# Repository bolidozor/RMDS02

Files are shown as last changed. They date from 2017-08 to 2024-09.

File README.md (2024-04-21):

# Radio Meteor Detection Station RMDS02F

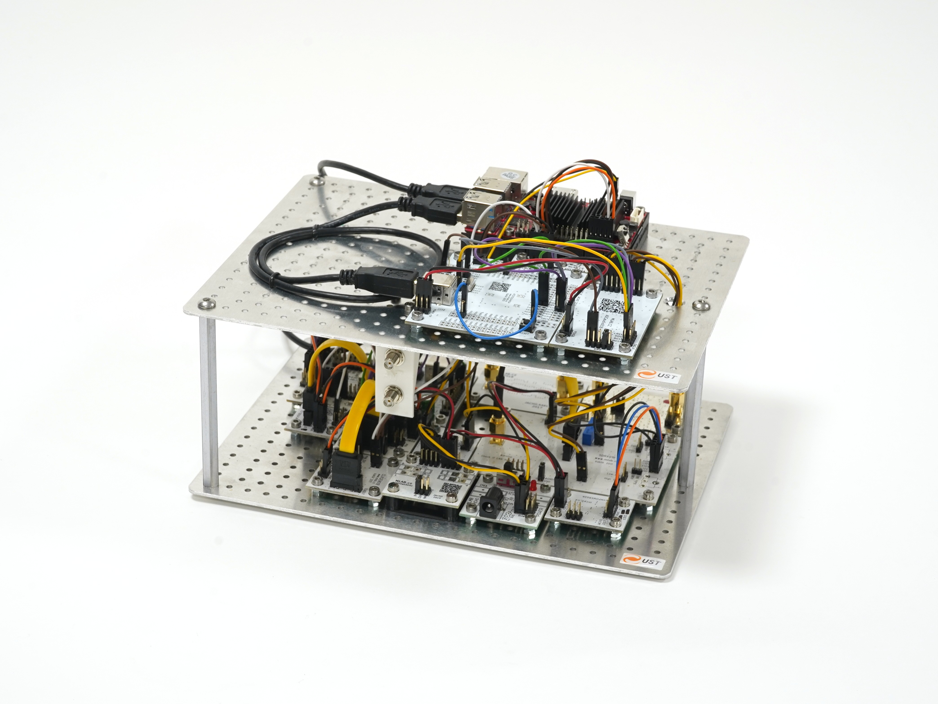
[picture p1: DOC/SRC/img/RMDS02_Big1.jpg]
RMDS02 Station RMDS02E station


The Radio Meteor Detection Station RMDS02F is a state-of-the-art system utilizing a software-defined radio (SDR) receiver set specifically configured for the detection of meteor trails using radio signals. The primary source of detection signals is the military GRAVES radar, which offers superior stability and power output, enabling effective meteor detection across nearly all of Europe. The station does not need any maitanance. The only requirement is power supply and internet connection on the observation site. 

## Features

- **Software-Defined Radio (SDR)**: The core of the RMDS02F is its SDR receiver, which allows for advanced signal processing techniques to be applied, enhancing detection capabilities.
- **GPS Synchronization**: The system includes GPS time and frequency synchronization which aids in determining inter-station reflection variations and the Doppler shift of the detected signals.
- **Enhanced Power Supply**: The station's power supply system has been upgraded to ensure reliable and consistent operation.
- **Single Board ARM Computer**: The station utilizes a single board ARM computer to process data and manage the detection system.
- **SDR-Widget Digitalization**: Signals are digitized using an SDR-Widget, ensuring high-quality data capture for advanced analysis.

## Advantages of Using GRAVES Radar

Utilizing the GRAVES military radar signal provides several advantages over traditional methods that use TV transmitters for meteor detection:
- **High Stability and Reliability**: The military-grade transmission offers unmatched signal stability and consistency.
- **Powerful Transmission**: With its enormous power output, the GRAVES radar system can cover a vast geographic area, making it possible to detect meteors throughout Europe.

## Description

The RMDS02F is an advanced radio meteor trail detection system. It is designed for accurate and efficient detection of meteors by utilizing the reflective properties of meteor trails in the upper atmosphere. The integration of GPS provides time and frequency stabilization that is crucial for analyzing inter-station signal variations and capturing Doppler shifts in the meteor trail reflections.

For further information and updates, please refer to the [Bolidozor documentation](https://wiki.bolidozor.cz/doku.php?id=en:rmds).

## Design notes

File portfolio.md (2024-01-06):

---
title: "Radio Meteor Detection Station"
excerpt: "The RMDS02 is the basic SDR receiver set for radio detection of meteor trails."
header:
  image: products/RMDS/DOC/SRC/img/RMDS02E_Big.jpg
  teaser: products/RMDS/DOC/SRC/img/RMDS02E_Big.jpg
  overlay_color: "#000"
  overlay_filter: "0.5"
  overlay_image: products/RMDS/DOC/SRC/img/RMDS02E_Big.jpg
---

# Radio Meteor Detection Station RMDS02E

The device presents the basic SDR receiver set for radio detection of meteor trails. Compared to other methods, its main advantage is in the fact that it uses a software-defined receiver that enables various advanced signal processing techniques.

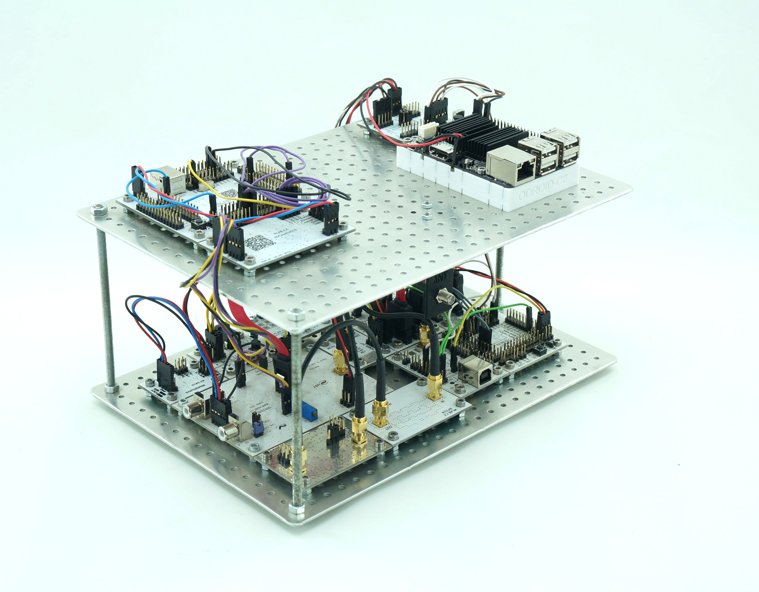
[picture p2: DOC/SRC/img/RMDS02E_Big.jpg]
RMDS02E Station RMDS02E station


## Meteor detection using GRAVES radar

The advantages of using the signal from military GRAVES radar, compared to the conventional observations using TV transmitters, include the stability and enormous power output of the military system transmission. This makes it possible to utilize it in almost every country in Europe.

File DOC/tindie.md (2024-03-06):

Embark on an unparalleled journey into the cosmos with the latest Radio Meteor Detection Station (RMDS). Designed for the technically savvy amateur astronomer, RMDS combines cutting-edge software-defined radio (SDR) technology with precision engineering to offer an unmatched meteor observation experience.

**🔭 Key Features:**

- **High-Precision SDR Technology:** Utilize state-of-the-art SDR for real-time meteor trail detection, capturing every celestial event with exceptional clarity.
- **Integration with GRAVES Radar:** Leverage the powerful and stable signal of the military-grade GRAVES radar, ensuring comprehensive coverage across Europe for reliable meteor detection.
- **Community Collaboration:** Join a network of stations through initiatives like [Bolidozor](https://www.bolidozor.cz/), fostering a collaborative environment for data sharing and analysis.
- **Advanced Data Analysis:** With shared platforms, contribute to and benefit from a collective pool of meteor detection data, enhancing scientific inquiry and understanding.

**🌠 Technical Specifications:**

- **SDR-Based Detection Module:** Tailored high dynamic signal processing, enabling the capture of meteor trails with high sensitivity.
- **Optimized Antenna System:** Optionally includes a ground-plane antenna designed for signal reception even from a balcony.
- **Customizable Software Interface:** Feature-rich software for detailed analysis, including real-time monitoring, data logging, and visualization tools.
- **Robust Construction:** Self-tuning SDR ensures year-round operation in a variety of climates.

**💡 Ideal for**

- Amateur astronomers seeking a dive into radio astronomy and meteor detection.
- Science educators and researchers looking for a reliable tool to enhance study and observation.
- Tech enthusiasts interested in the application of SDR technology in astronomical observations.

**Elevate Your Astronomy Experience**

The RMDS is more than just a tool; it's your gateway to exploring the mysteries of the night sky in ways previously invisible. With its superior technology, collaborative potential, and comprehensive support, the RMDS is the perfect addition to the tools of any amateur astronomer ready to take their passion to new heights.

Embark on a celestial journey with the Radio Meteor Detection Station and witness the wonders of the universe like never before.

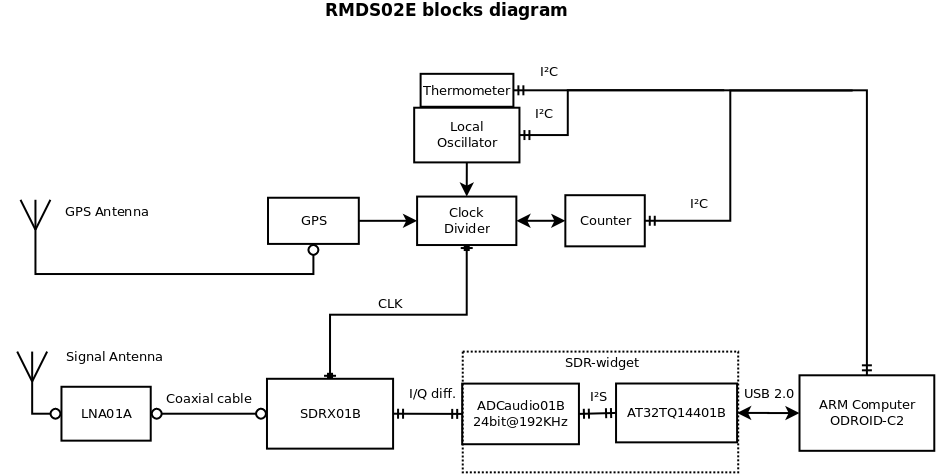
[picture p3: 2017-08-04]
DOC/SRC/img/RMDS02E_blocks.png

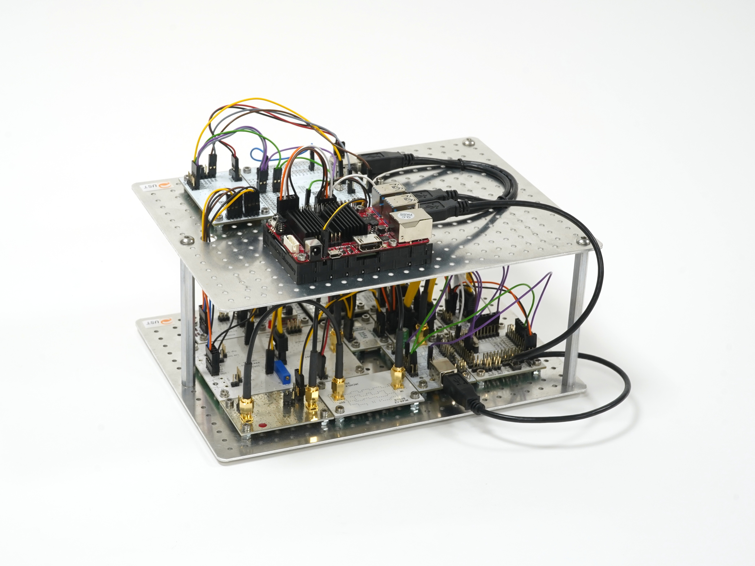
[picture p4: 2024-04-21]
DOC/SRC/img/RMDS02_Big2.jpg

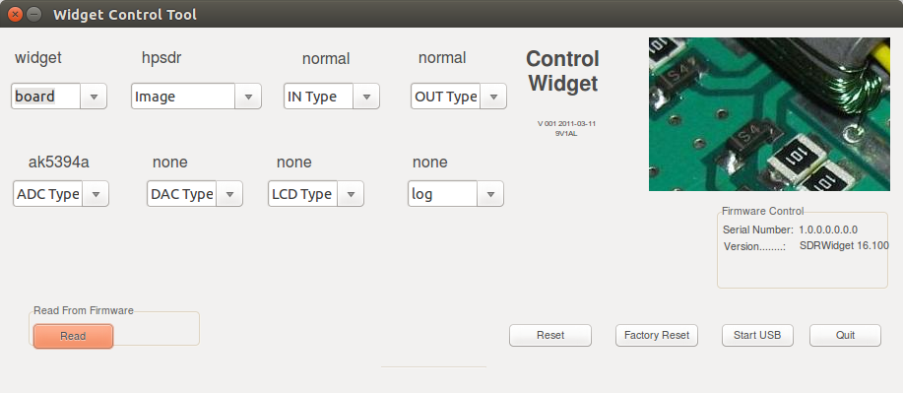
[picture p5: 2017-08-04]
DOC/SRC/img/SDR-widget_settings.png

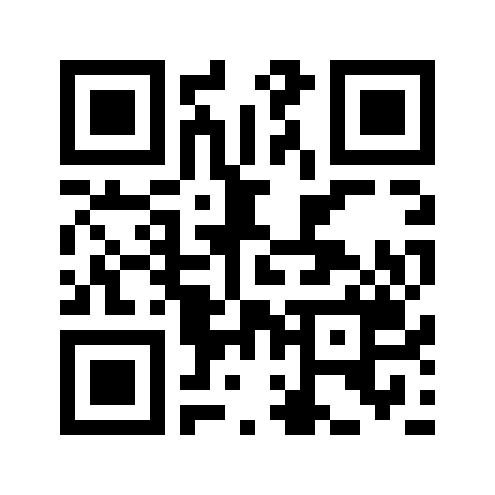
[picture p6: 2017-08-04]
DOC/SRC/img/Bolidozor_web_QR.png

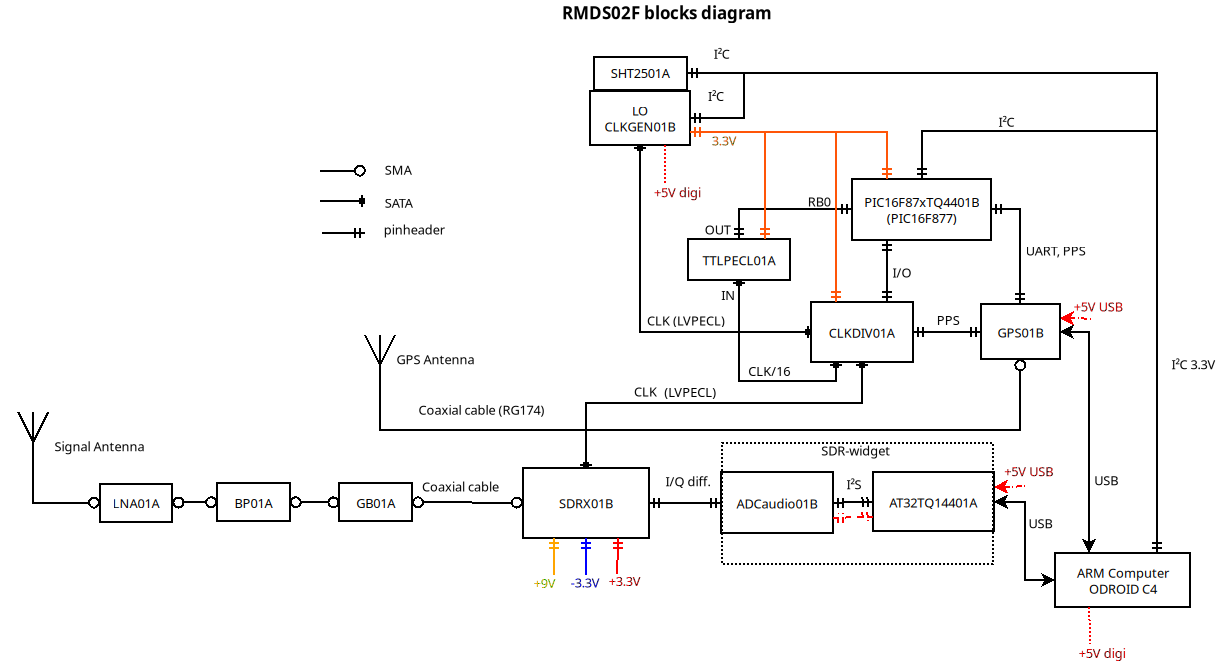
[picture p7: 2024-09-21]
SCH/RMDS02_station.png

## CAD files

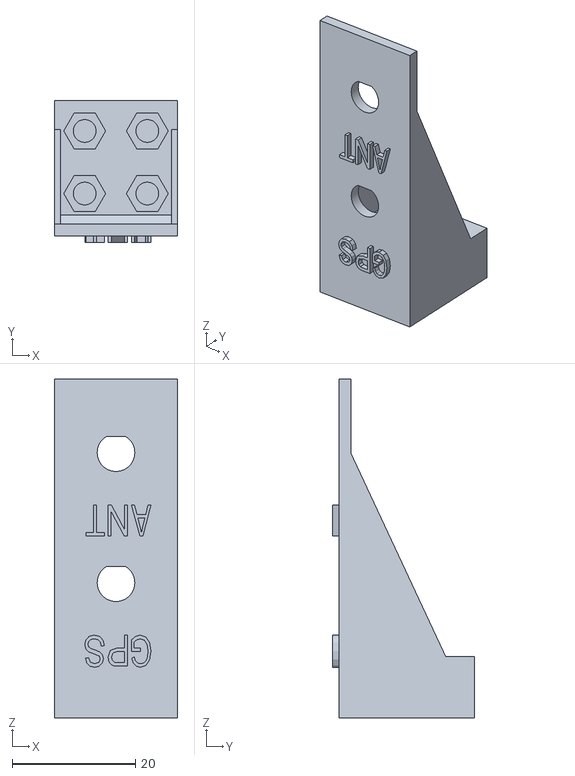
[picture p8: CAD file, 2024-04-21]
CAD/connectors_holder.stl
20.0 x 23.0 x 55.0

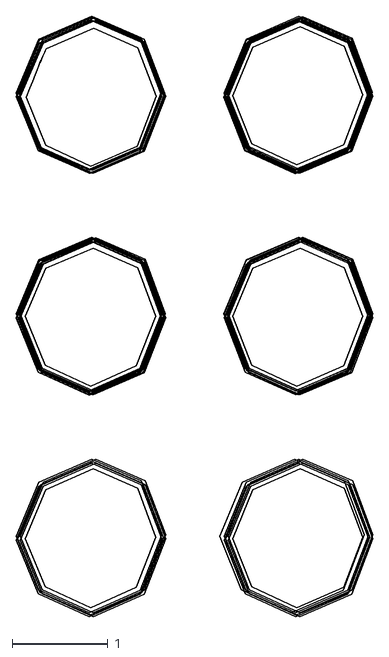
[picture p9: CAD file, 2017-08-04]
CAD/src/braille.dxf
3.72 x 6.26

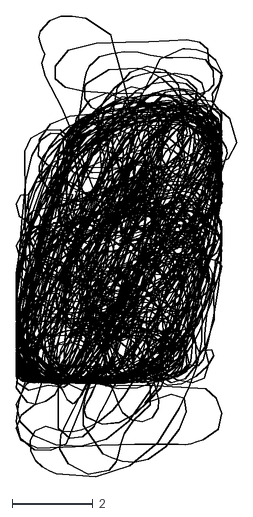
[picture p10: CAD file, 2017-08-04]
CAD/src/knewave.dxf
5.46 x 11.4

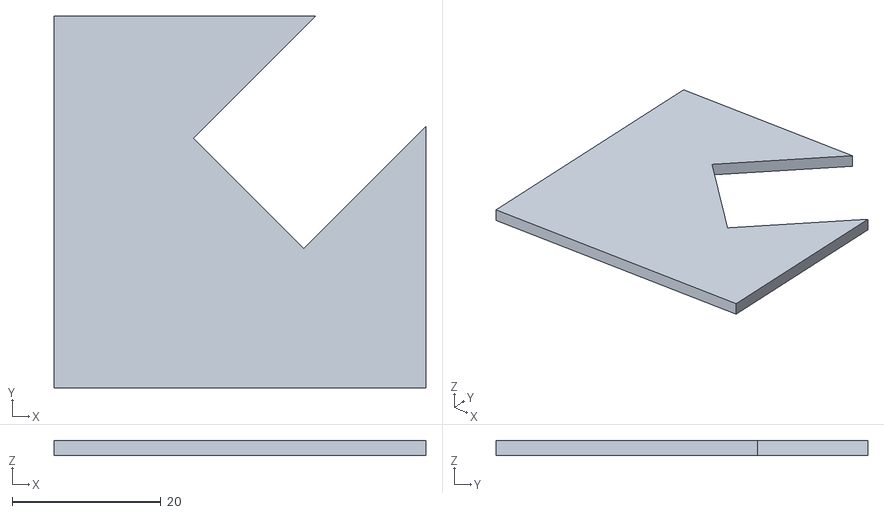
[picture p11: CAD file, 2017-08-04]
CAD/template_terarium_pad.stl
50.0 x 50.0 x 2.00

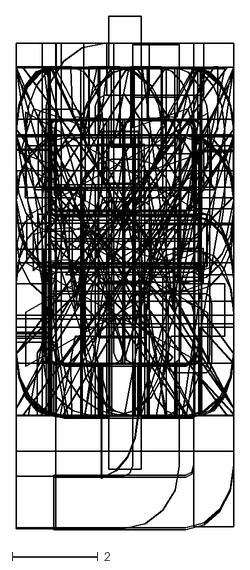
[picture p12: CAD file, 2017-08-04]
CAD/src/orbitron.dxf
5.08 x 12.0

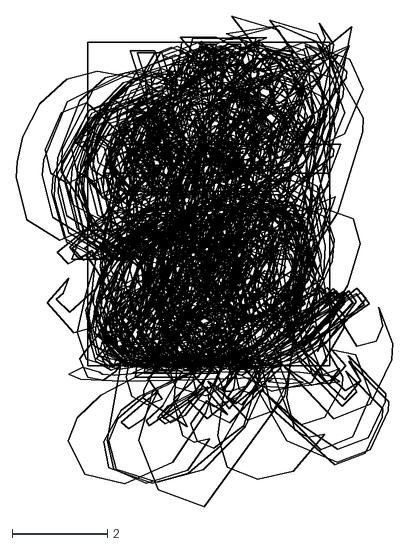
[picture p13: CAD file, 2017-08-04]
CAD/src/BlackRose.dxf
7.90 x 10.3

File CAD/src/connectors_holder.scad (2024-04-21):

use<Write.scad>
$fn=100;

x_size = 20;           // horizontal outer size of the pedestal. 
y_size = 20;           // 
mount_hole = 3.5;
nut_size = 6.8;
SMA_dia = 6.1;
SMA_flat = 3.15;
thickness = 10;         //
wall_thickness = 2;
height = 55;

mount_hole = 3.7;
clear = 0.175;

MLAB_grid = 10.16;

x_holes = floor(x_size / MLAB_grid);
y_holes = floor(y_size / MLAB_grid);

MLAB_grid_xoffset = (x_size - (x_holes * MLAB_grid))/2;
MLAB_grid_yoffset = (y_size - (y_holes * MLAB_grid))/2;

//Top part

union () {

    difference(){
        cube([x_size, y_size, height]);
        translate([1, 0, 0]) cube([x_size-2, y_size+0.1, height+0.1]);
        translate([-0.1, y_size, 0]) rotate([25, 0, 0]) cube([x_size+0.2, y_size+10, height+10]);
    }

    difference () {
                cube([x_size, y_size , thickness ]);

// MLAB grid holes
        grid_list = [for (j = [MLAB_grid_xoffset : MLAB_grid: x_size], i = [MLAB_grid_yoffset :MLAB_grid: y_size])  [j, i] ];
            
        for (j = grid_list) {
                translate (concat(j, [0]))
                    cylinder (h = 3, r= nut_size/2, $fn=6);
                translate (concat(j, [3.2]))  // one solid layer for slicer (the holes will be pierced on demand )
                    cylinder (h = thickness /3, r= mount_hole/2, $fn=30);
                translate (concat(j, [6.0]))
                    cylinder (h = 10, r= nut_size/2, $fn=6);
        }  
    };
// vertical to horizontal brick connection
    translate ([ 0, 0, thickness - sqrt(2 * wall_thickness*wall_thickness) / 2])  // move to correct positon on square diagonal  
        rotate([45,0,0])
            cube([x_size, wall_thickness , wall_thickness ]);

    difference  () {

        translate ([0, -wall_thickness, 0])    // vertical brick
            cube([y_size, wall_thickness , height ]);
        
// SMA connector holes
        translate ([ x_size/2, wall_thickness/2, (height - thickness)/3  + thickness - SMA_dia/2])    
            rotate([90,0,0]) {
                difference  () {
                    cylinder (h = 2*wall_thickness, r= SMA_dia/2, $fn=50);
                        translate([ 0, SMA_flat , wall_thickness/2 + wall_thickness ]) 
                            cube([SMA_dia, 1 , thickness ], center=true);
                }
            }

        translate ([ x_size/2, wall_thickness/2, 2*(height - thickness)/3  + thickness  + SMA_dia/2 ])    
            rotate([90,0,0]){
                difference  () {
                    cylinder (h = 2*wall_thickness, r= SMA_dia/2, $fn=50);
                        translate([ 0, SMA_flat , wall_thickness/2 + wall_thickness ]) 
                            cube([SMA_dia, 1 , thickness ], center=true);
                }
 
           }
           
    }
// texts
    
        translate ([ x_size/2, wall_thickness/2, (height - thickness)/3  + thickness - SMA_dia/2])    
            rotate([90,0,0]) {
                translate([ 0, -11, wall_thickness/2 + wall_thickness ]) 
                    rotate([0,0,180])
                        write("GPS",h=5,t=2,space= 1.1, font = "Letters.dxf", center=true);
            }
            
            translate ([ x_size/2, wall_thickness/2, 2*(height - thickness)/3  + thickness  + SMA_dia/2 ])    
            rotate([90,0,0]){
                translate([ 0, -11, wall_thickness/2 + wall_thickness]) 
                    rotate([0,0,180])
                        write("ANT",h=5,t=2, space= 1.1, font = "Letters.dxf",center=true);
            }
               
           
}

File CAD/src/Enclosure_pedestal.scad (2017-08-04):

pedestal_height = 130;  // height of pedestal
x_size = 250;           // horizontal outer size of the aquarium pedestal. 
y_size = 300;           // 
thickness = 10;         // thickness of walls
rim_height = 10;        // height of upper rim for fixing the aquarium in position.

difference () {
	cube([x_size, y_size ,pedestal_height]);
        translate ([thickness, thickness, pedestal_height - rim_height)
	        cube([x_size - 2* thickness, y_size - 2* thickness, thickness]);

	    cube([x_size - 2* thickness, y_size - 2* thickness, pedestal_height - rim_height - thickness]);
}

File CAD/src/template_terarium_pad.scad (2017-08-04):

hrana=50;
vzdalenost_od_rohu=37;
sila_materialu=2;

pad_sirka=21;
pad_delka=50;

difference()
{
//základní materiál
cube([hrana,hrana,sila_materialu],false);

rotate([0, 0, -45])
translate([0,vzdalenost_od_rohu+ pad_delka/2, 0])
cube([pad_sirka,pad_delka,2*sila_materialu+0.1],true);
    }

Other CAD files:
CAD/src/Letters.dxf
CAD/src/terarium_pad.scad
CAD/src/Write.scad

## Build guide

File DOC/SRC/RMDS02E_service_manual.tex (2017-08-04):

\documentclass[12pt,a4paper,oneside]{article}
\usepackage[colorlinks=true]{hyperref}
\usepackage[utf8]{inputenc}
\usepackage[czech]{babel}
\usepackage{graphicx}
\usepackage{pdfpages}
\textwidth 16cm \textheight 25cm
\topmargin -1.3cm 
\oddsidemargin 0cm
\pagestyle{empty}
\begin{document}
\title{Radiová meteorická detekční stanice RMDS02D}
\author{Jakub Kákona, kaklik@mlab.cz }
\maketitle

\begin{abstract}
Servisní manuál k rádiové detekční stanici RMDS02D sítě Bolidozor.
\end{abstract}

\begin{figure} [htbp]
\begin{center}
\includegraphics [width=120mm] {./img/RMDS02D_showcase1.JPG} 
\end{center}
\end{figure}

\begin{figure} [b]
\includegraphics [width=25mm] {./img/Bolidozor_web_QR.png} 
\end{figure}

\newpage
\tableofcontents

\section{Základní technické parametry}
\begin{table}[htbp]
\begin{center}
\begin{tabular}{|c|c|p{5cm}|}
\hline
\multicolumn{1}{|c|}{Parametr} & \multicolumn{1}{|c|}{Hodnota} & \multicolumn{1}{|c|}{Poznámka} \\ \hline
Napájení analogových obvodů & $\pm$12V &  cca 35mA \\ \hline
Napájení digitálních obvodů & 2x +5V &  2A \\ \hline
Napájení předzesilovače  & 9-12V &  500 mA \footnote{Chráněno vratnou PTC pojistkou 750mA na desce přijímače} \\ \hline
Pracovní Frekvenční rozsah  & 0,5 - 200 MHz & Obvykle 143.05 MHz $\pm$ 192 kHz \\ \hline
Vzorkování I/Q signálu  & 16bit@96kHz & \\ \hline
Celkový zisk & 60-90 dB & Volitelně podle konfigurace LNA \footnote{Lze ovlivnit jumperem na desce přijímače}\\ \hline
Celkové šumové číslo & $<$ 10 dB & \\ \hline
Minimální detekovatelný signál & -135dBm  &  Při konfiguraci v síti Bolidozor.\\ \hline
Přesnost časové synchronizace &  65ns (1$\sigma$) &  Používán signál GPS L1.\\ \hline
Rozlišení kontrolního měření frekvence LO &  0.1 Hz &  Přesnost je závislá na kvalitě signálu GPS.\\ \hline
\end{tabular}
\end{center}
\end{table}

\newpage

\section{Konstrukce detekční stanice}

\begin{figure}[htbp]
\begin{center}
\includegraphics [width=120mm] {../../SCH/RMDS02D_system.png} 
\end{center}
\caption{Konstrukce antény používané na detekční stanici.}
\end{figure}

\subsection{Přijímací obvody}

Rádiový

\subsection{SDR přijímač}

V přijímací stanici je využíván přijímač MLAB SDRX01B \cite{SDRX01B_pdf}. Jde o SDR přijímač zkonstruovaný původně pro účely amatérské radioastronomie a je proto optimalizovaný pro realizaci škálovatelných rádiových systémů. Přijímač vyžaduje externí lokální oscilátor, který je v případě této konstrukce realizovaný zapojením modulu CLKGEN01B s obvodem Si570, který je řízen přes sběrnici I2C.  Frekvence tohoto lokálního oscilátoru je měřena 3x za minutu a logována do souboru. Po změření se navíc frekvence automaticky koriguje na nastavenou hodnotu. Fázový šum lokálního oscilátoru je maximálně –105~dBc/Hz (Při offsetu 100~Hz)

\begin{figure}[htbp]
\begin{center}
\includegraphics [width=120mm] {./img/SDRX01B_Top_Big.JPG} 
\end{center}
\caption{Hlavní modul přijímače SDRX01B}
\end{figure}

Díky měření frekvence lokálního oscilátoru je ve stanici v podstatě obsažena GPSDO kmitočtová reference, která napájí přijímač. Výstupem přijímače je tak komplexní I/Q signál, který je v této verzi stanice digitalizován externí USB zvukovou kartou Behringer UCA 202 U-CONTROL. Tento audio kodek vzorkuje 48kHz s rozlišením 16bit ve dvou kanálech.  Zvuková karta bude v následující verzi stanice nahrazena digitalizační jednotkou SDR-Widget. Která už může mít vzorkovací hodinový signál též odvozen od hlavního lokálního oscilátoru. 

\subsection{Časová synchronizace}

Časová synchronizace je velmi dúležitá ve vědeckých měřeních. Konstrukce využívá dvě metody časové synchronizace NTP a signál z GPS.  NTP je využíváno pro časovou synchronizaci systémových hodin staničního počítače a používá se i pro generování názvů výstupních datových souborů. Přesnost tohoto synchronizačního kanálu závisí na kvalitě internetového připojení, resp době pingu k NTP serveru.  Proto je na stanici zaveden ještě zdroj časových značek z GPS, který umožňuje značkovat výstupní data s rozlišením až na vzorkovací frekvenci digitalizační jednotky. 
Jako GPS přijímač je ve stanici využíván MLAB modul GPS01A s čipsetem uBlox-LEA6. Použitá GPS anténa je keramická patch s integrovaným předzesilovačem.

\subsubsection{Měření frekvence lokálního oscilátoru}

Stanice je vybavena automatizovaným systémem kontroly lokálního oscilátoru. Zařízení umožňuje měření frekvence lokálního oscilátoru oproti dlouhodobému časovému normálu z GPS. Měření se provádí tak, že signál z lokálního oscilátoru generovaného modulem CLKGEN01B se vydělí modulem CLKDIV01A a vydělený výstupní signál je veden do čítače v PIC16F887. Kde jsou na hrubo počítány tako vydělené hodinové pulzy. 
Modul GPS01A je pak nastaven tak, aby generoval 100us dlouhý impuls každých celých 10s UT.  Tento impuls je pak využit ke zahradlování děličky CLKDIV01A.  Zároveň impuls vede na vstup přerušení PIC16F887 a ten pak provede vyčtení čítače a interních stavů děličky tím, že projde všechny možné dělící poměry a přečte výstupní stav děličky. Výsledkem je absolutně změřený počet pulzů za 10s.  Toto číslo je následně uloženo v registrech mikrokontroleru PIC16F887. Vyčtení těchto registrů proběhne ze staničního počítače přes sběrnici I2C každou 5. 25. a 45. sekundu UT času. \footnote{Měření je takto rozloženo díky tomu, že obsluha I2C probíhá také pod přerušením a při vyčítání může dojít k poškození měřené hodnoty vynecháním přerušení obsluhy čítače.}
Protože při zahradlování děličky dojde k odpojení lokálního oscilátoru od směšovače v SDRX01B, tak na výstupním signálu se objeví impuls s širokým frekvenčním spektrem, který slouží jako časová značka ve výstupních datech.  Časová synchronizace tak zároveň přesně značkuje výstupní data hodinami odvozenými z GPS signálu. Tvar těchto časových značek je navíc odvozen od impulzní odezvy přijímacího řetězce, takže na něm lze pozorovat případné nežádoucí změny parametrů. 

\subsection{Staniční počítač}

Jako staniční počítač je využíván Hardkernel ODROID-U3, což je čtyřjádrový počítač postavený na architektuře ARM. K tomuto počítači je ještě obvykle připojen USB flash disk, který slouží jako krátkodobé uložiště pro zaznamenaná data.  Technické parametry použitého ARM počítače jsou následující: 

\begin{itemize}
\item 1.7GHz Quad-Core processor and 2GByte RAM
\item 10/100Mbps Ethernet with RJ-45 LAN Jack
\item 3 x High speed USB2.0 Host ports
\item Audio codec with headphone jack on board
\item GPIO/UART/I2C ports
\end{itemize}

Komponenty stanice jsou k počítači připojeny přes rozhraní USB: (Zvuková karta, GPS přijímač) a přes rozhraní I2C: (Lokální oscilátor, měření frekvence)

\begin{figure}[htbp]
\begin{center}
\includegraphics [width=140mm] {./img/u3rev05boarddetail.jpg} 
\end{center}
\caption{Deska počítače Hardkernel ODROID-U3}
\end{figure}

\section{Software stanice}

Na staničním počítači je nainstalovaný operační systém linux Lubuntu 14.04 LTS včetně grafického rozhraní xfce.  Grafické rozhraní je na stanici využíváno pro zobrazování stavových informací. (živý waterfall, stav GPS, stav uploadu dat). S datovým tokem z přijímače je zacházeno jako s širokopásmým audio signálem. Proto je pro rozvod  datového toku použit audiosystém JACK. Příklad rozvodu signálu je na obrázku \ref{qjackctl}.

\begin{figure}[htbp]
\centering
\includegraphics [width=120mm] {./img/JACK_audio.png} 
\caption{Rozvod audio signálu v systému JACK.}
\label{qjackctl}
\end{figure}

Jack audio server navíc umožňuje přenášet stream přes lokální síť ethernet a aktuální tok spektra z přijímače je tak možné sledovat i na jiných počítačích viz obr. \ref{Pysdr}.

\begin{figure}[htbp]
\centering
\includegraphics [width=120mm] {./img/meteor_pysdr.jpg} 
\caption{Vzdálené zobrazení toku spektra v programu PySDR. S meteorem označeným MIDI packetem.}
\label{Pysdr}
\end{figure}

\subsection{Záznam dat}

Data jsou na stanici zaznamenávána programem radio-observer, který běží jako klient systému jack, počítá FFT spektra a detekuje meteory podle intenzity signálu v oblasti, kde je předpokládán signál od vysílače. Pokud v této oblasti dojde ke zvýšení intenzity signálu o prahovou hodnotu nad šumem tak je detekován meteor.  Při detekci meteoru vznikne několik záznamů, jednak náhled na frekvenční oblast spektra, kde meteor byl detekován. Potom záznam surových vzorků z přijímače a také záznam do metadatového souboru s parametry signálu detekovaného meteoru (délka odrazu, intenzita signálu, atd.). Datové výstupy jsou ve formátu FITS s kompresí RICE, buď jako navzorkované signály a nebo předpočítané spektrogramy. Všechna naměřená data jsou veřejně dostupná na datovém serveru. 

\subsection{Odesílání záznamů}

Naměřená data jsou ještě na stanici setříděna do stromové adresářové struktury podle času. A následně uploadována přes rsync na hlavní datový server space.astro.cz.

\subsection{Správa stanice}

Na stanici běží ještě další pomocné aplikace, jako sshd server, pro vzdálený přístup a skripty pro ladění a kontrolu lokálního oscilátoru.

\begin{thebibliography}{99}
\bibitem{GRAVES_book}{GRAVEs source book} 
\href{http://www.fas.org/spp/military/program/track/graves.pdf}{http://www.fas.org/spp/military/program/track/graves.pdf}

\bibitem{LNA01A_wiki}{Nízkošumový zesilovač LNA01A} 
\href{http://wiki.mlab.cz/doku.php?id=cs:lna}{http://wiki.mlab.cz/doku.php?id=cs:lna}

\bibitem{SDRX01B_pdf}{Softwarově definovaný přijímač SDRX01B} 
\href{http://www.mlab.cz/Designs/HAM\%20Constructions/SDRX01B/DOC/SDRX01B.cs.pdf}{http://www.mlab.cz/Designs/HAM\%20Constructions/SDRX01B/DOC/SDRX01B.cs.pdf}

\bibitem{LNA01A_wiki}{Síť Bolidozor} 
\href{http://wiki.bolidozor.cz/}{http://wiki.bolidozor.cz/}

\bibitem{meteor_distance}{Meteor distance parameters} 
\href{http://www.amsmeteors.org/richardson/distance.html}{http://www.amsmeteors.org/richardson/distance.html}

\end{thebibliography}
\end{document}

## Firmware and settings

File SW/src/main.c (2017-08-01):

// Atomic counter with I2C and RS232 output

// Usage conditions:
// 1. The first I2C or RS232 readout can be performed minimally 20 s after power up.
// 2. The I2C internal address 0 has to be read first.
// 3. An I2C readout can be performed at 15-th, 35-th and 55-th second of UTC. 
//
// Counter gives 32 bit value:
// I2C register address 0 = LSB
// I2C register address 3 = MSB

#define ID "$Id: main.c 3741 2014-10-25 22:30:12Z kakl $"
#include "main.h"
#use i2c(SLAVE, Fast, sda=PIN_C4, scl=PIN_C3, force_hw, address=0xA2) 

#include <string.h>

#define LED    PIN_B3   // heartbeat indicator
#define SEL0   PIN_E0   // external counter division ratio
#define SEL1   PIN_E1   // external counter division ratio
#define MR     PIN_E2   // external counter master reset
#define CLKI   PIN_C0   // internal counter input

unsigned int32 count;   // count per second

int1 fire_setup;        // flag for sending setup to GPS

#define BUF_LEN 4
int8 buffer[BUF_LEN];   // I2C buffer     
int8 address=0;

unsigned int16 of=0; // count of overflow

// 1x 100 us per 10 s UTC synchronised; 40 configuration bytes
char cmd[50]={40, 0xB5, 0x62, 0x06, 0x31, 0x20, 0x00, 0x00, 0x00, 0x00, 0x00, 0x32, 0x00, 0x00, 0x00, 0x80, 0x96, 0x98, 0x00, 0xE0, 0xC8, 0x10, 0x00, 0x64, 0x00, 0x00, 0x00, 0x00, 0x00, 0x00, 0x00, 0x00, 0x00, 0x00, 0x00, 0x73, 0x00, 0x00, 0x00, 0xC6, 0x51};

// configure GPS
void setup_GPS()
{ 
   int n;
   int len;
   len=cmd[0];
   for (n=1;n<=len;n++) putc(cmd[n]); 
}

#INT_SSP
void ssp_interupt ()
{
   int8 incoming, state;

   state = i2c_isr_state();

   if(state < 0x80)                    //Master is sending data
   {     
      incoming = i2c_read();           // Read byte

      if(state == 1)                   //Second received byte is address of register
      {
         address = incoming;         
      }

      if(state == 2)                   //Thid received byte are configuration data
      {             
         if ((address==0)&&(incoming==0)) 
         {
            fire_setup = 1; // Write configuration to the GPS if configuration data length is 0
         }
         else
         {
            cmd[address] = incoming; // Store byte to configuration sentence
         }
      }
   }
   if(state == 0x80)                     //Master is requesting data
   {
      //i2c_read();    // Dummy read of I2C device address
      
      if(address == 0)  // Change buffer atomically at reading of the first byte
      {
         buffer[0]=make8(count,0);
         buffer[1]=make8(count,1);
         buffer[2]=make8(count,2);
         buffer[3]=make8(count,3);
      }
      if(address <= BUF_LEN) 
      {
         i2c_write(buffer[address]); // Prepare one byte to SSP buffer
      }
      else
      {
         i2c_write(0x00); // There is nothing to prepare, so zero
      }
   }

   if(state == 0x81)                     //Master is requesting data
   {
      i2c_write(buffer[1]); // Prepare next byte to SSP buffer
   }
   if(state == 0x82)                     //Master is requesting data
   {
      i2c_write(buffer[2]); // Prepare next byte to SSP buffer
   }
   if(state == 0x83)                     //Master is requesting data
   {
      i2c_write(buffer[3]); // Prepare next byte to SSP buffer         
   }

   if(state > 0x83)                     //Master is requesting data
   {
      i2c_write(0x00); // There is nothing to prepare, so zero
   }
}



#int_EXT  // Interrupt from 1PPS (RB0)
void  EXT_isr(void) 
{
   unsigned int16 countH;
   unsigned int8  countL;
   int16 of2;
   
   of2=of;                 // read overflow counter   
   countH=get_timer1();    // read internal counter
   countL=0;
   output_low(SEL0);
   output_low(SEL1);
   countL=input(CLKI);     // read bit 0 of external counter
   output_high(SEL0);
//   output_low(SEL1);
   countL|=input(CLKI)<<1; // read bit 1 of external counter
   output_low(SEL0);
   output_high(SEL1);
   countL|=input(CLKI)<<2; // read bit 2 of external counter
   output_high(SEL0);
//   output_high(SEL1);
   countL|=input(CLKI)<<3; // read bit 3 of external counter

   output_toggle(LED); // heartbeat
   output_low(MR);   // External counter Master Reset
   output_high(MR);
   set_timer1(0);    // Internal counter reset
   of=0;             // Overflow counter reset
   
   count=((unsigned int32)of2<<20)+((unsigned int32)countH<<4)+(unsigned int32)countL; // concatenate 

//   printf("%010Lu\r\n", count);    
}

#int_TIMER1  // Interrupf from overflow
void  TIMER1_isr(void) 
{
   of++;
}

void main()
{
   setup_adc_ports(NO_ANALOGS|VSS_VDD);
   setup_adc(ADC_OFF);
//   setup_spi(SPI_SS_DISABLED);  //must not be set if I2C are in use! 
   setup_timer_0(RTCC_INTERNAL|RTCC_DIV_1);
   setup_wdt(WDT_2304MS);
   setup_timer_1(T1_EXTERNAL|T1_DIV_BY_1);
   setup_timer_2(T2_DISABLED,0,1);
   setup_comparator(NC_NC_NC_NC);
   setup_vref(FALSE);

   restart_wdt();
   delay_ms(1000);
   restart_wdt();
   
   // setup GPS
   setup_GPS();

   ext_int_edge( L_TO_H );       // set 1PPS active edge
   enable_interrupts(INT_TIMER1);
   enable_interrupts(INT_EXT);
   enable_interrupts(INT_SSP); 
   enable_interrupts(GLOBAL);    
   
   buffer[0]=0x0; // Clear I2C output buffer
   buffer[1]=0x0;
   buffer[2]=0x0;
   buffer[3]=0x0;

   //printf("\r\ncvak...\r\n");
   
   fire_setup = 0;

   while(true)
   {      
      restart_wdt();
      delay_ms(1000);
      if (fire_setup) 
      {
         setup_GPS(); // Write configuration to the GPS
         fire_setup = 0;
      }
      output_toggle(LED); // heartbeat
      //printf("%X %X %X %X\r\n", buffer[0],buffer[1],buffer[2],buffer[3]);
      //printf("%010Lu\r\n", count);    
   }
}

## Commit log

2017-08-04 RMDS02D documentation moved from MLAB svn repository to github.
    [BlackRose.dxf, Enclosure_pedestal.scad, Letters.dxf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]
2017-08-04 New documentation for RMDS02E station.
    [connectors_holder.amf, terarium_pad.amf, terarium_pad_fixing_part.amf]
2024-04-21 Zpevneni drzaku, solve #6
    [connectors_holder.scad, connectors_holder.stl]
2024-09-19 Rename schematics files.
2024-09-19 Update block schematics.
